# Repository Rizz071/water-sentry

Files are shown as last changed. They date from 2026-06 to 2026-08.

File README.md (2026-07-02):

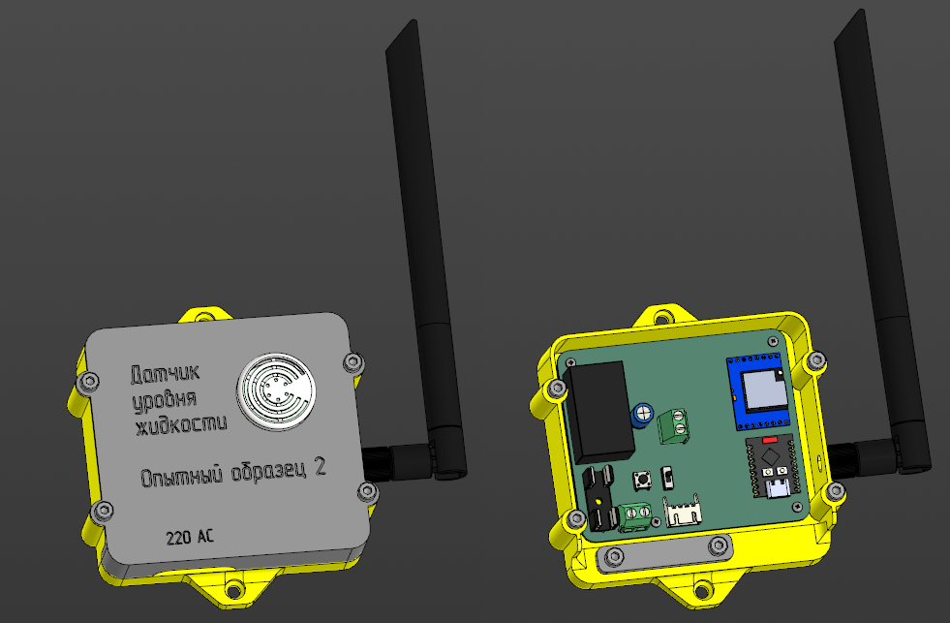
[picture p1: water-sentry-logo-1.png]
Блок управления датчиком уровня жидкости


# WaterSentry 🌊🏹

**WaterSentry** — это полностью автономная система дальнего беспроводного мониторинга уровня жидкости и предотвращения затоплений. 

Проект разработан для условий, где **абсолютно недоступны или ненадежны классические каналы связи**: нет Wi-Fi, интернета, сотовых сетей (GSM) и абонентской платы. Связь между удаленным датчиком и базовой станцией осуществляется напрямую по радиоканалу LoRa.

---

## 💡 Как это работает

1. **Удаленный датчик** устанавливается в месте возможного разлива (подвал, колодец, резервуар, насосная). Раз в 5 минут он отправляет короткий сигнал «я жив» (*heartbeat*).
2. **В случае перелива** датчик мгновенно выходит из режима ожидания и отправляет внеочередной пакет с флагом аварии.
3. **Базовая станция**, находящаяся на значительном удалении (в доме, диспетчерской), принимает сигнал, включает световую индикацию тревоги и запускает мощную сирену (зуммер) для привлечения внимания человека.

---

## 🚀 Ключевые особенности

* **Независимость от инфраструктуры:** Никаких сим-карт, роутеров и облачных сервисов. Прямая связь «точка-точка».
* **Огромная дальность:** Благодаря модулям LoRa на частоте 433 МГц сигнал уверенно пробивает железобетонные перекрытия, стены и распространяется на большие расстояния в условиях сложного рельефа.
* **Экстремальный минимализм протокола:** Данные упакованы в компактную структуру размером всего **6 байт**. Это минимизирует время работы передатчика в эфире (*Time on Air*), повышает пробивную способность радиосигнала и экономит энергию.
* **Промышленная надежность:** Код написан на **чистом Си** под нативный фреймворк **ESP-IDF v5.x**.
* **Гибкая отладка

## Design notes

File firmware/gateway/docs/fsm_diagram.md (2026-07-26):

# Water Sentry Gateway — State Machine Diagram

## Sensor Slot FSM (per slot, 5 independent instances)

```mermaid
stateDiagram-v2
    direction TB

    [*] --> EMPTY : Power on / no saved MAC

    state EMPTY {
        [*] --> Idle_Empty
    }
    note right of EMPTY : LED: OFF\nBuzzer: SILENT

    state PAIRING {
        [*] --> Waiting
    }
    note right of PAIRING : LED: BLUE\nBuzzer: SILENT\nTimeout: 60 sec

    state OK {
        [*] --> Normal
    }
    note right of OK : LED: GREEN\nBuzzer: SILENT\nPing → brief blink-off (100ms)

    state OFFLINE {
        [*] --> Lost
    }
    note right of OFFLINE : LED: YELLOW\nBuzzer: WARNING (beep)\nShort press → ack buzzer

    state ALARM {
        [*] --> WaterDetected
    }
    note right of ALARM : LED: RED\nBuzzer: ALARM (slow beep)

    %% Transitions from EMPTY
    EMPTY --> PAIRING : Short press button\n(empty slot)

    %% Transitions from PAIRING
    PAIRING --> OK : Pairing packet received\nfrom sensor
    PAIRING --> EMPTY : Short press (cancel)\nOR 60s timeout\n→ mac_addr cleared, NVS saved

    %% Transitions from OK
    OK --> ALARM : Water alarm packet\n(STATUS_BIT_ALARM_WATER)
    OK --> OFFLINE : No packets for\nSENSOR_TIMEOUT_MS (30s)
    OK --> PAIRING : Long press (≥3s)\n→ mac_addr cleared, NVS saved

    %% Transitions from OFFLINE
    OFFLINE --> OK : Any packet received\nfrom sensor
    OFFLINE --> EMPTY : Long press (≥3s)\n→ mac_addr cleared, NVS saved\n(forced in system_manager)

    %% Transitions from ALARM
    ALARM --> OK : Ping packet (no alarm)\nfrom sensor
    ALARM --> OFFLINE : No packets for\nSENSOR_TIMEOUT_MS (30s)
```

### Valid transition matrix (from `sensor_fsm.c`)

| From ↓ \ To → | EMPTY | PAIRING | OK | OFFLINE | ALARM |
|:---|:---:|:---:|:---:|:---:|:---:|
| **EMPTY** | — | ✅ | — | — | — |
| **PAIRING** | ✅ | — | ✅ | — | — |
| **OK** | — | ✅ | — | ✅ | ✅ |
| **OFFLINE** | ✅ | — | ✅ | — | — |
| **ALARM** | — | — | ✅ | ✅ | — |

> **Note:** `OFFLINE → PAIRING` is **not** in `sensor_fsm.c`'s `is_valid_transition()`.  
> It is forced directly in `system_manager.c` (long press handler) by clearing `mac_addr` and setting `state = SLOT_PAIRING` manually, bypassing `set_state()`.

---

## Button Event Flow

```mermaid
flowchart TD
    Press[Button Press\n(hardware-debounced)] --> HoldCheck{Held ≥ 3000ms?}

    HoldCheck -->|Yes| LongPress[EVENT_BTN_LONG_PRESS]
    HoldCheck -->|No, released| ShortPress[EVENT_BTN_PAIR_PRESSED]

    ShortPress --> SlotState{Slot State?}
    SlotState -->|EMPTY| StartPairing[Enter PAIRING]
    SlotState -->|PAIRING| CancelPairing[Cancel → EMPTY\nSave NVS]
    SlotState -->|OFFLINE| AckBuzzer[Acknowledge buzzer\noffline_acked = true]
    SlotState -->|OK / ALARM| Ignore[Do nothing]

    LongPress --> BoundCheck{Slot State?}
    BoundCheck -->|OK / ALARM / OFFLINE| ForcePairing[Clear mac_addr\nEnter PAIRING\nSave NVS]
    BoundCheck -->|EMPTY / PAIRING| Ignore2[Do nothing]
```

### Button timing constants (from `app_config.h`)

| Parameter | Value | Description |
|---|---|---|
| `BUTTON_POLL_MS` | 20 ms | ADC polling interval |
| Long press threshold | 3000 ms | Hardcoded in `buttons_service.c` |

---

## System Boot Sequence

```mermaid
sequenceDiagram
    participant Main as app_main()
    participant NVS as NVS HAL
    participant Buzzer as Buzzer HAL
    participant LED as LED Strip HAL
    participant Bus as Event Bus
    participant FSM as Sensor FSM
    participant Mgr as System Manager
    participant UI as UI Controller
    participant LoRa as LoRa Service
    participant BTN as Buttons Service

    Main->>NVS: nvs_hal_init()
    Main->>Buzzer: buzzer_hal_init()
    Note over Buzzer: Creates buzzer_task (prio 3)
    Main->>LED: led_strip_hal_init()
    Main->>Bus: event_bus_init()
    Main->>NVS: nvs_hal_load_blob("sensors", "dev_list")
    Main->>FSM: sensor_fsm_init(slots, mac_list, 5)
    Main->>Mgr: system_manager_init(slots, 5)
    Note over Mgr: Creates sys_manager_task (prio 5)
    Main->>UI: ui_controller_init()
    Note over UI: Creates ui_task (prio 3)
    Main->>LoRa: lora_service_init()
    Note over LoRa: Creates lora_rx_task (prio 5)
    Main->>BTN: buttons_service_init()
    Note over BTN: Creates buttons_polling_task (prio 5)
```

---

## System Architecture — Event Flow

```mermaid
flowchart LR
    subgraph HAL["Hardware Abstraction Layer"]
        LORA_HAL[LoRa HAL\nSX1278 SPI]
        BTN_HAL[Buttons HAL\nADC read]
        LED_HAL[LED Strip HAL\nRMT driver]
        BUZZ_HAL[Buzzer HAL\nGPIO + timer\n<buzzer_task>]
        NVS_HAL[NVS HAL\nFlash storage]
    end

    subgraph SERVICES["Service Layer"]
        LORA_SVC[LoRa Service\nFreeRTOS task\n<lora_rx_task>]
        BTN_SVC[Buttons Service\nFreeRTOS task\n<buttons_polling_task>\n+ debounce + long press]
        UI_CTRL[UI Controller\nFreeRTOS task\n<ui_task> 50ms\nLED + Buzzer]
        EV_BUS{{Event Bus\nFreeRTOS queue}}
        SYS_MGR[System Manager\nFreeRTOS task\n<sys_manager_task> 1s\nOrchestrator]
        FSM[Sensor FSM\nPure logic\n5 slots]
    end

    LORA_HAL -->|lora_rx_packet_t| LORA_SVC
    BTN_HAL -->|uint8_t raw| BTN_SVC

    LORA_SVC -->|EVENT_LORA_PACKET_RX| EV_BUS
    BTN_SVC -->|EVENT_BTN_PAIR_PRESSED| EV_BUS
    BTN_SVC -->|EVENT_BTN_LONG_PRESS| EV_BUS

    EV_BUS -->|event_t| SYS_MGR
    SYS_MGR -->|read/write state| FSM
    SYS_MGR -->|save/load| NVS_HAL

    FSM -->|sensor_slot_t[5]| UI_CTRL
    UI_CTRL -->|led_color_t[5]| LED_HAL
    UI_CTRL -->|buzzer_state_t| BUZZ_HAL
```

---

## Event Bus — Message Catalog

| Event Type | Producer | Consumer | Payload |
|---|---|---|---|
| `EVENT_BTN_PAIR_PRESSED` | Buttons Service | System Manager | `button_num` (1..5) |
| `EVENT_BTN_LONG_PRESS` | Buttons Service | System Manager | `button_num` (1..5) |
| `EVENT_LORA_PACKET_RX` | LoRa Service | System Manager | `mac_addr`, `packet_type` (status bits) |
| `EVENT_PERIODIC_TICK` | System Manager (self) | System Manager | — (generated on queue timeout) |
| `EVENT_PAIRING_TIMEOUT` | System Manager (self) | System Manager | — (generated on queue timeout) |

---

## LED Color Map

| State | Red | Green | Blue | Visual |
|---|-----|---|---|---|
| EMPTY | 0 | 0 | 0 | ⚫ Off |
| PAIRING | 0 | 0 | 255 | 🔵 Blue |
| OK | 0 | 255 | 0 | 🟢 Green |
| OK (ping blink) | 0 | 0 | 0 | ⚫ Brief off (100ms) |
| OFFLINE | 0 | 255 | 255 | 🟡 Yellow (Green+Blue) |
| ALARM | 255 | 0 | 0 | 🔴 Red |

---

## Buzzer Patterns

| Condition | Pattern | Code Constant | Meaning |
|---|---|---|---|
| Any ALARM slot | 1000ms ON / 1000ms OFF | `BUZZER_STATE_ALARM` | Water leak detected |
| Unacked OFFLINE slot(s) | 200ms ON / 200ms OFF | `BUZZER_STATE_WARNING` | Sensor connection lost |
| All OFFLINE acked / no issues | OFF (always low) | `BUZZER_STATE_SILENCED` | Normal operation |

### Buzzer state priority (in `ui_controller.c`)

```
has_alarm → BUZZER_STATE_ALARM       (highest)
has_unacked_offline → BUZZER_STATE_WARNING
else → BUZZER_STATE_SILENCED         (lowest)
```

---

## Task List (FreeRTOS)

| Task | Stack | Priority | Period | WDT | Created by |
|---|---|---|---|-----|---|
| `lora_rx_task` | 3072 | 5 | ~10ms (poll) | ✅ | `lora_service_init()` |
| `buttons_polling_task` | 3072 | 5 | 20ms | ✅ | `buttons_service_init()` |
| `sys_manager_task` | 4096 | 5 | 1s (event timeout) | ✅ | `system_manager_init()` |
| `ui_task` | 3072 | 3 | 50ms | ✅ | `ui_controller_init()` |
| `buzzer_task` | 3072 | 3 | varies (100ms/400ms/2000ms) | ✅ | `buzzer_hal_init()` |

### Task periods for buzzer_task (from `buzzer_hal.c`)

| Buzzer State | Cycle | vTaskDelay |
|---|---|---|
| `BUZZER_STATE_SILENCED` | OFF → wait 100ms → repeat | 100ms |
| `BUZZER_STATE_WARNING` | ON 200ms → OFF 200ms → repeat | 200ms |
| `BUZZER_STATE_ALARM` | ON 1000ms → OFF 1000ms → repeat | 1000ms |

---

## Configuration Constants (from `app_config.h`)

| Constant | Value | Description |
|---|---|---|
| `MAX_SENSORS` | 5 | Number of sensor slots |
| `EVENT_QUEUE_LENGTH` | 10 | System event queue capacity |
| `LORA_RX_QUEUE_LENGTH` | 20 | LoRa RX packet queue capacity |
| `BUTTON_POLL_MS` | 20 ms | ADC polling interval |
| `SENSOR_TIMEOUT_MS` | 30000 ms (30s) | Sensor considered offline after this |
| `PAIRING_TIMEOUT_MS` | 60000 ms (60s) | Pairing mode auto-cancel |

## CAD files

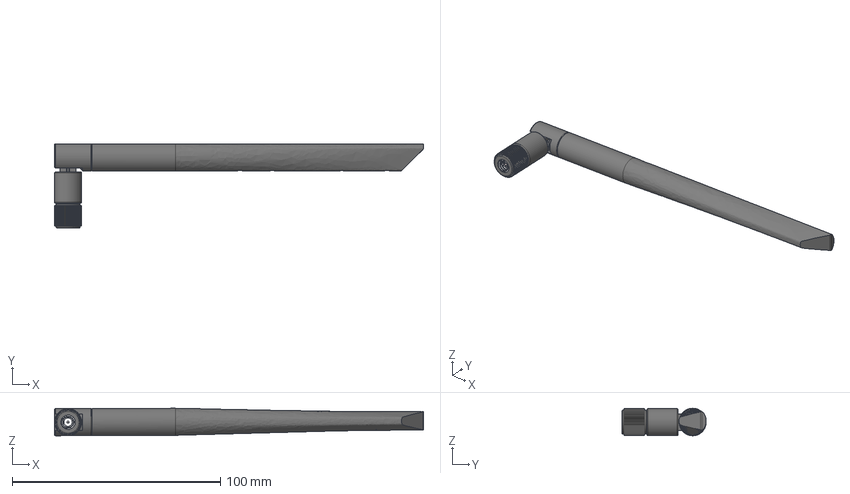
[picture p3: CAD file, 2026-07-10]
hardware/gateway/enclosure/Antenna 868mhz 5dbi 90dg.step
177.0 x 40.5 x 13.2 mm
SMA sleeve
SMA
Sleeve yoke
emitter yoke
emitter tube
emitter cover

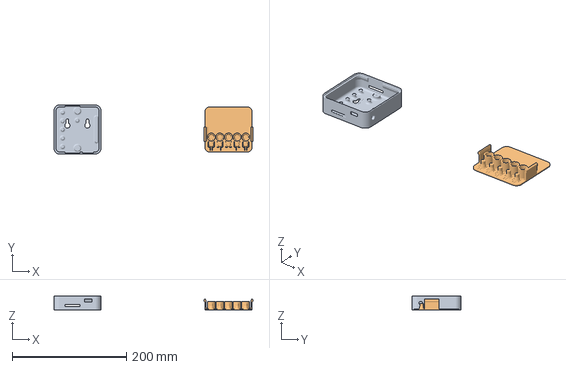
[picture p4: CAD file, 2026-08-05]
hardware/gateway/enclosure/Manufacture/Базовая станция Исп 1.3mf
347.8 x 86.0 x 25.0 mm
Корпус блока управления датчика уровня жидкости.stp
Крышка корпуса базовой станции.stp

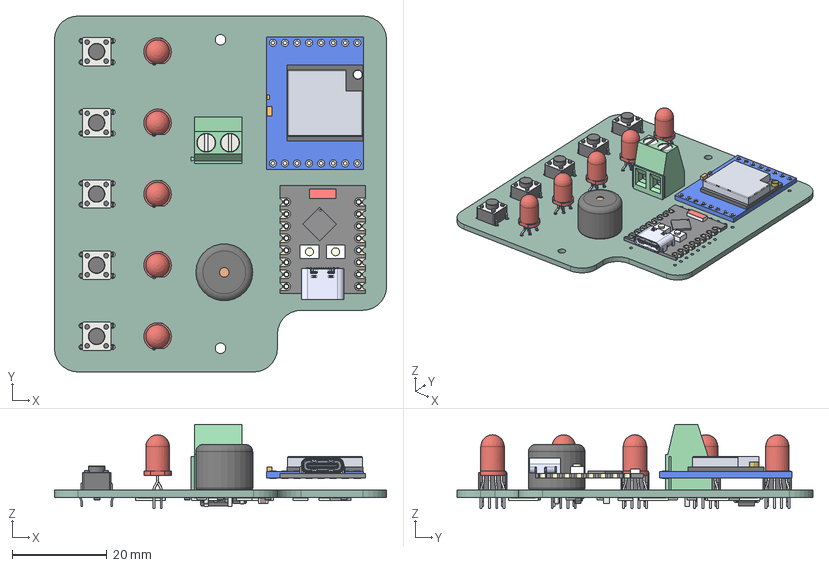
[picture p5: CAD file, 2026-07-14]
hardware/gateway/KiCAD/sensor_3d.step
70.0 x 75.0 x 17.8 mm
SW_PUSH_6mm_h5mm x 5
Buzzer_12x95RM76
LED_D5.0mm-4_RGB_Staggered_Pins x 5
TerminalBlock_Phoenix_MKDS-1,5-2_1x02_P5.00mm_Horizontal
Board c3mini
USB C
components (other)^ESP32-C3 SuperMini
R_2512_6332Metric x 8
R_0805_2012Metric x 10
SOT-23
C_0805_2012Metric
SOT-223
gatFA11_PCB

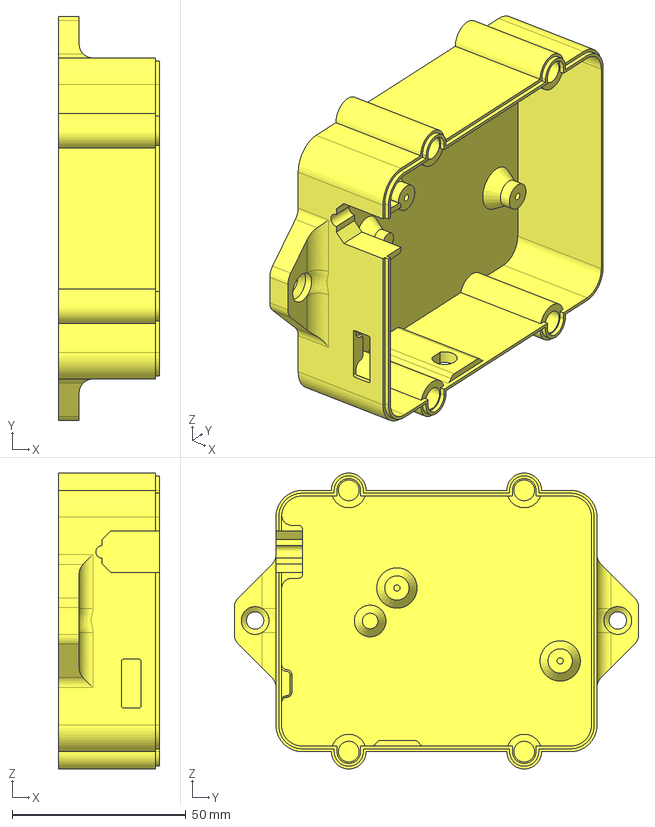
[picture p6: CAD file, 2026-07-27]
hardware/sensor/enclosure/Manufacture/Корпус блока управления датчика уровня жидкости.stp
29.2 x 116.4 x 85.2 mm

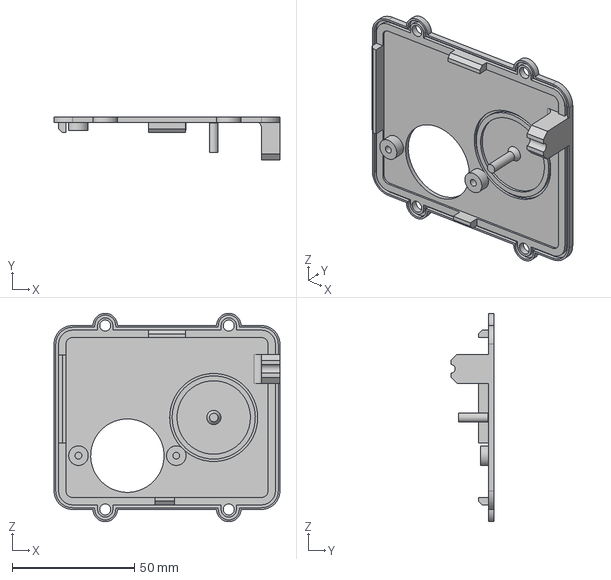
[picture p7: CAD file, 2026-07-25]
hardware/sensor/enclosure/Крышка блока управления датчиком уровня жидкости.stp
92.4 x 17.7 x 85.2 mm

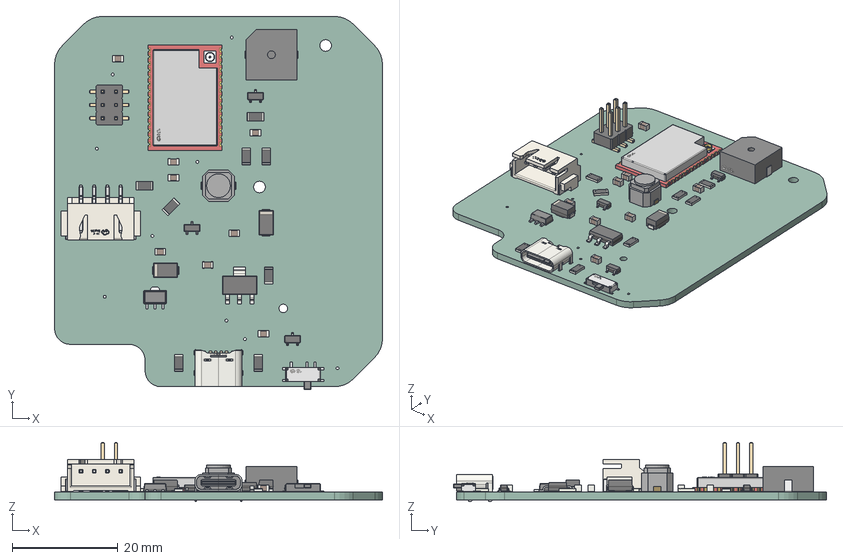
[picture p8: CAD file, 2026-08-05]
hardware/sensor/KiCAD/sensor_3d.step
62.0 x 70.6 x 11.2 mm
C_0805_2012Metric x 8
R_1206_3216Metric x 8
D_SMA x 2
SOT-23 x 3
PinHeader_2x03_P254mm_Vertical_SMD
COMM-SMD_30P-L20.0-W14.0-P1.27
USB_C_Receptacle_GCT_USB4125-xx-x_6P_TopMnt_Horizontal
BUZ-SMD_L9.6-W9.6-H5.0
pin_1
pin_2
SOT-89-3_L4.3-W2.5-H1.6-LS4.1-P1.50
SW-SMD_3P-L6.6-W2.7-LS7.8-P1.50
CONN-SMD_XH2.50-WS-4P
SOT-223
active_sender_PCB

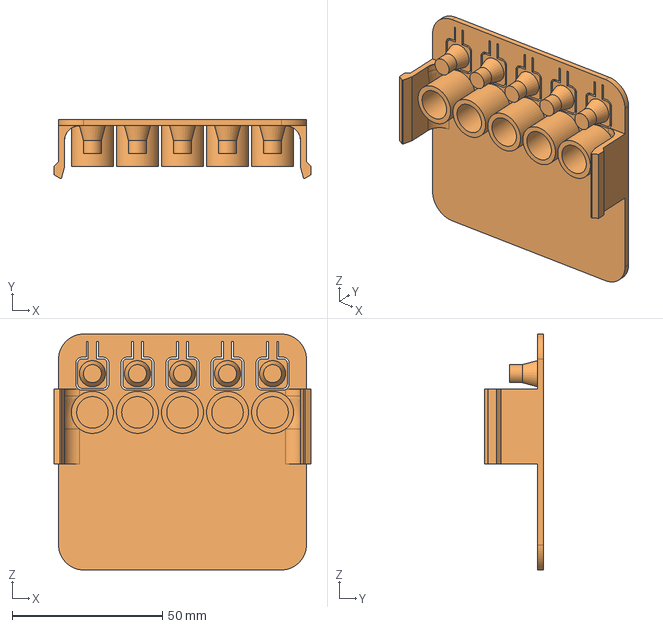
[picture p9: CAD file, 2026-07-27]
hardware/gateway/enclosure/Manufacture/Крышка корпуса базовой станции.stp
85.6 x 19.5 x 78.6 mm

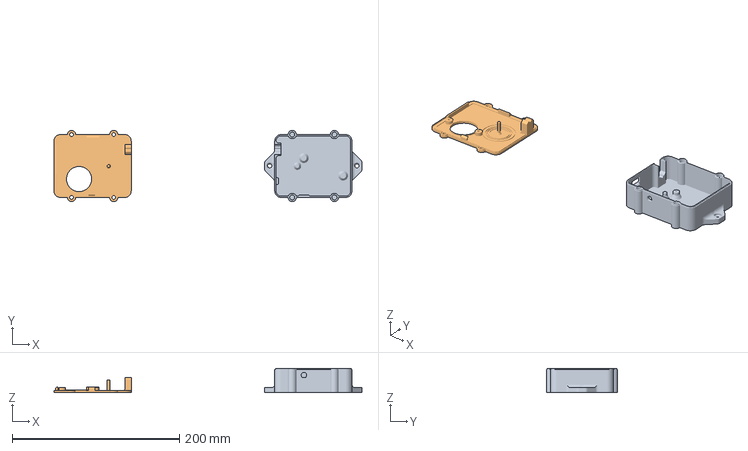
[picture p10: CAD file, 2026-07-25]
hardware/sensor/enclosure/Manufacture/Блок управления датчиком уровня жидкости.3mf
368.4 x 85.2 x 29.2 mm
Корпус блока управления датчика уровня жидкости.stp
Крышка блока управления датчиком уровня жидкости.stp

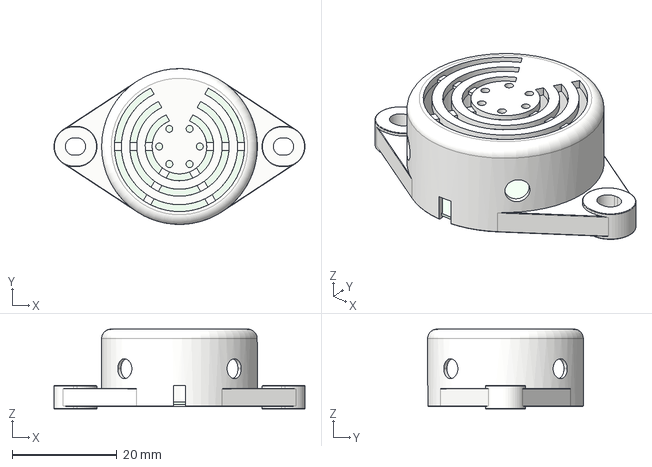
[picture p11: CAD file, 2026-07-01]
hardware/sensor/enclosure/Piezo Buzzer (3-24v, M3).step
48.0 x 29.8 x 15.3 mm

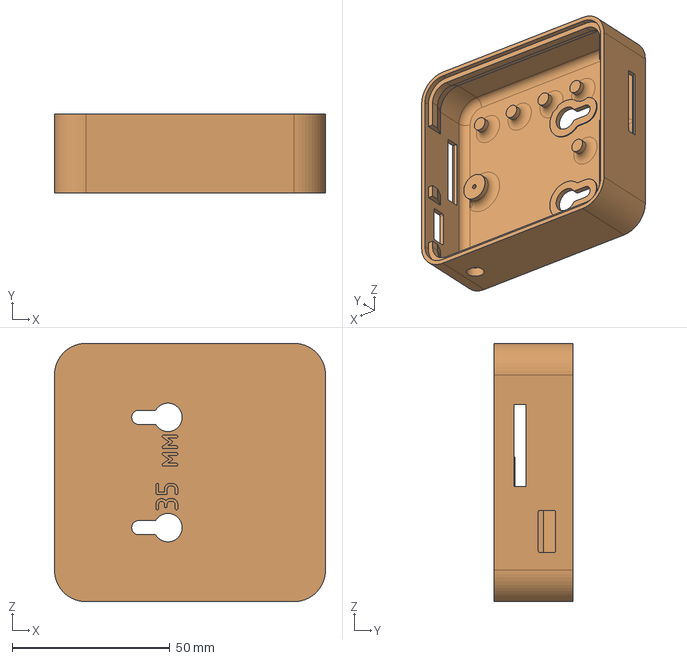
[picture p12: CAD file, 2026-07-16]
hardware/gateway/enclosure/Manufacture/Корпус блока управления датчика уровня жидкости.stp
86.0 x 25.0 x 82.0 mm

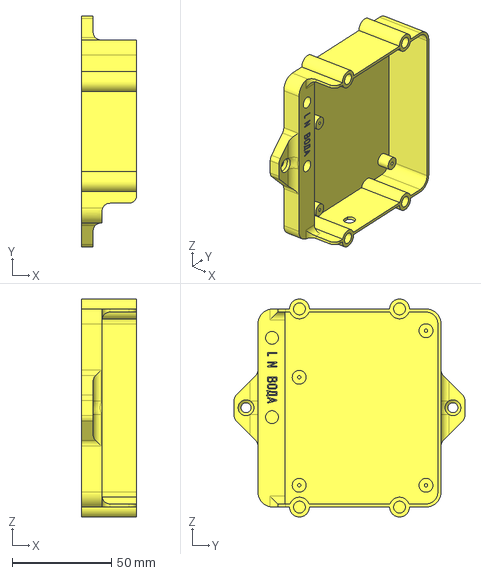
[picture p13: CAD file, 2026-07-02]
hardware/gateway/enclosure/Корпус блока управления датчика уровня жидкости.stp
28.0 x 116.4 x 110.0 mm

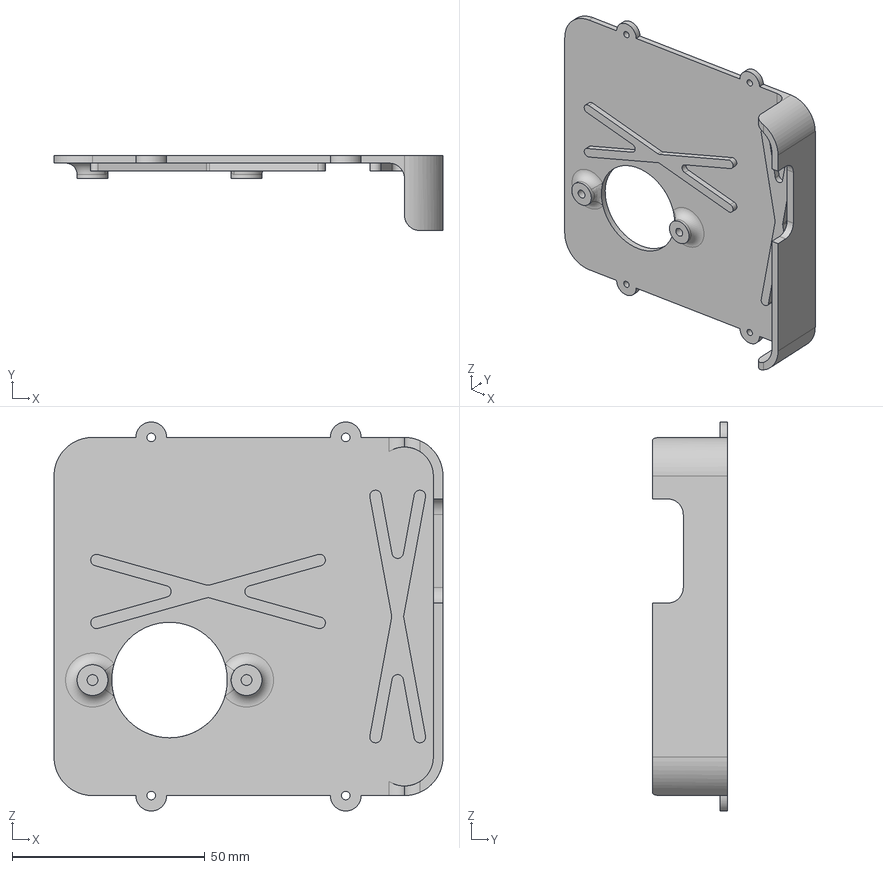
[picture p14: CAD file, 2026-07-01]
hardware/gateway/enclosure/Manufacture/Крышка блока управления датчиком уровня жидкости.stp
101.0 x 19.5 x 101.0 mm

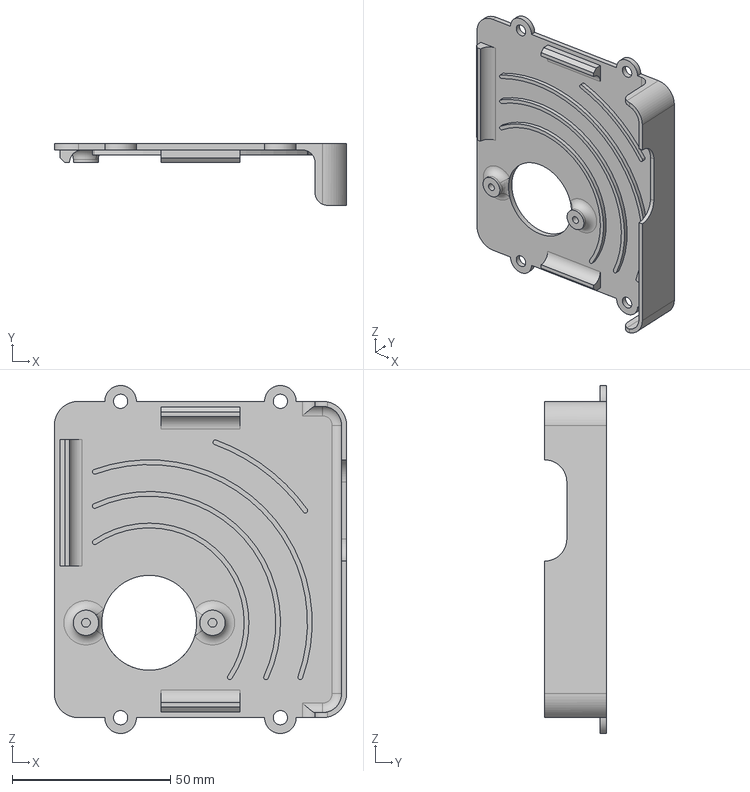
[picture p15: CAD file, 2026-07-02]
hardware/gateway/enclosure/Крышка блока управления датчиком уровня жидкости.stp
92.4 x 19.5 x 110.0 mm

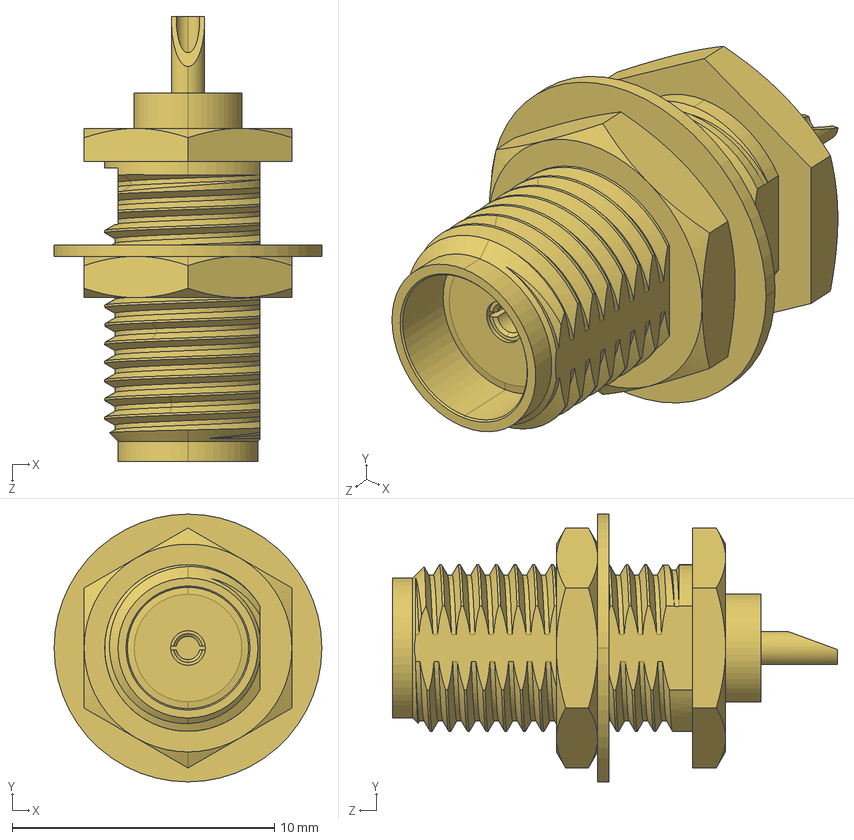
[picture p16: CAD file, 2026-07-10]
hardware/gateway/enclosure/1053072-1.STEP
10.2 x 10.2 x 17.0 mm

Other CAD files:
hardware/sensor/enclosure/Manufacture/Крышка блока управления датчиком уровня жидкости.stp
hardware/gateway/KiCAD/sensor_3d.stl
hardware/sensor/KiCAD/sensor_3d.stl

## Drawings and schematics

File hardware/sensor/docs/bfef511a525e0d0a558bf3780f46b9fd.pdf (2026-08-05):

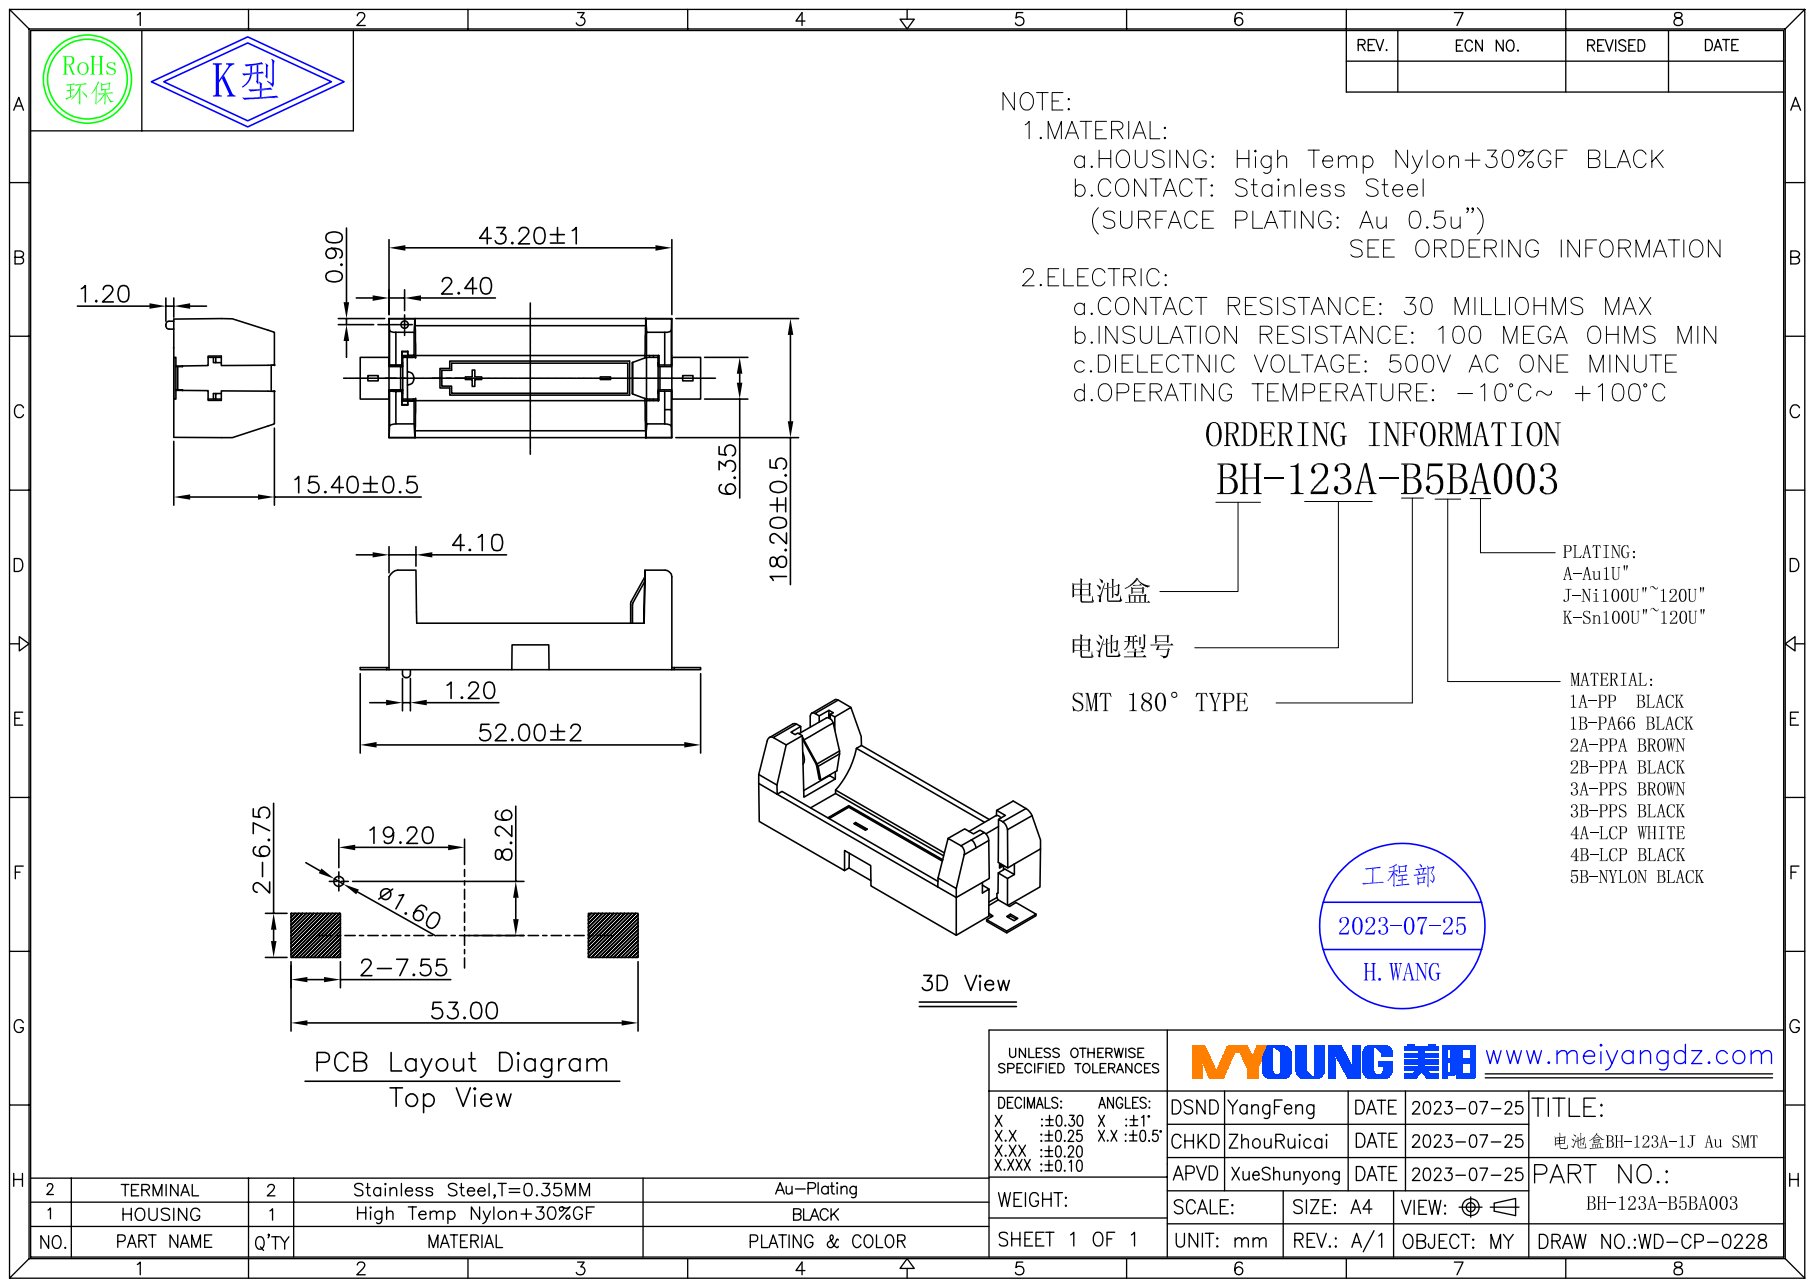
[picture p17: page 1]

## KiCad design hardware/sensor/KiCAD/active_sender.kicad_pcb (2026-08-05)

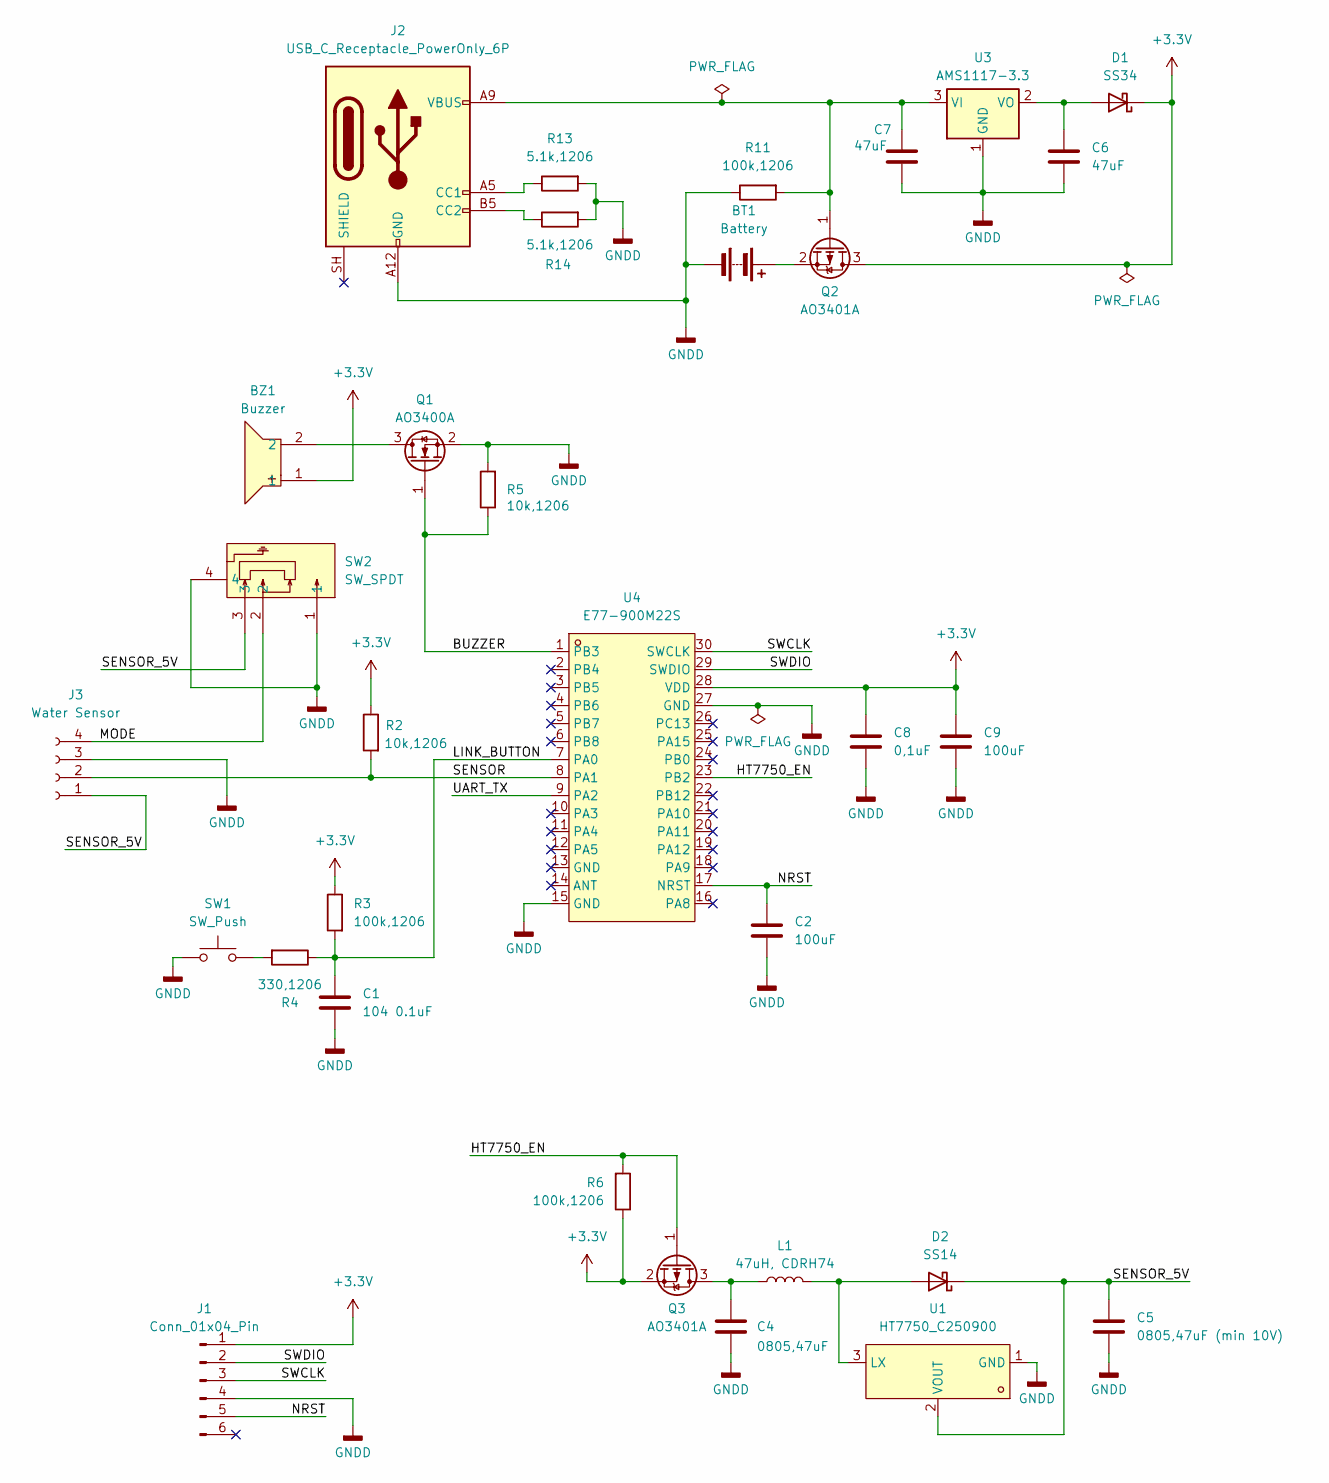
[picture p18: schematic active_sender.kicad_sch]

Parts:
BT1: Battery; CR123A-SMD_BH-123A-B5BA003
BZ1: Buzzer; Huaneng MLT-9650; MPN MLT-9650; LCSC Part C96127
C1: 104 0.1uF; C_0805_2012Metric_Pad1.18x1.45mm_HandSolder
C2, C9: 100uF; C_0805_2012Metric_Pad1.18x1.45mm_HandSolder
C4: 0805,47uF; C_0805_2012Metric_Pad1.18x1.45mm_HandSolder
C5: 0805,47uF (min 10V); C_0805_2012Metric_Pad1.18x1.45mm_HandSolder
C6, C7: 47uF; C_0805_2012Metric_Pad1.18x1.45mm_HandSolder
C8: 0,1uF; C_0805_2012Metric_Pad1.18x1.45mm_HandSolder
D1: SS34; D_SMA
D2: SS14; D_SMA
J1: Conn_01x04_Pin; PinHeader_2x03_P2.54mm_Vertical_SMD
J2: USB_C_Receptacle_PowerOnly_6P; USB_C_Receptacle_GCT_USB4125-xx-x-0190_6P_TopMnt_Horizontal
J3: Water Sensor; JST_XH_S4B-XH-SM4-TB_1x04-1MP_P2.50mm_Horizontal
L1: 47uH, CDRH74; L_7.3x7.3_H4.5
Q1: AO3400A; SOT-23
Q2, Q3: AO3401A; SOT-23
R2, R5: 10k,1206; R_1206_3216Metric_Pad1.30x1.75mm_HandSolder
R3, R6, R11: 100k,1206; R_1206_3216Metric_Pad1.30x1.75mm_HandSolder
R4: 330,1206; R_1206_3216Metric_Pad1.30x1.75mm_HandSolder
R13, R14: 5.1k,1206; R_1206_3216Metric_Pad1.30x1.75mm_HandSolder
SW1: SW_Push; SW_Push_1TS009xxxx-xxxx-xxxx_6x6x5mm
SW2: SW_SPDT; MSK12-C02; MPN MSK12C02; LCSC Part C431540
U1: HT7750_C250900; HT7750; MPN HT7750; LCSC Part C250900
U3: AMS1117-3.3; SOT-223-3_TabPin2
U4: E77-900M22S; COMM-SMD_30P-L20.0-W14.0-P1.27; MPN E77-900M22S; LCSC Part C5124422

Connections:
+3.3V: BZ1.1, C8.1, C9.1, D1.1 (K), J1.1, Q2.3 (D), Q3.2 (S), R2.1, R3.1, R6.1, U4.28 (VDD)
/BUZZER: Q1.1 (G), R5.1, U4.1 (PB3)
/HT7750_EN: Q3.1 (G), R6.2, U4.23 (PB2)
/LINK_BUTTON: C1.1, R3.2, R4.1, U4.7 (PA0)
/MODE: J3.4, SW2.2
/NRST: C2.1, J1.5, U4.17 (NRST)
/SENSOR: J3.2, R2.2, U4.8 (PA1)
/SENSOR_5V: C5.1, D2.1 (K), J3.1, SW2.3, U1.2 (VOUT)
/SWCLK: J1.3, U4.30 (SWCLK)
/SWDIO: J1.2, U4.29 (SWDIO)
/UART_TX: U4.9 (PA2)
GNDD: BT1.2 (-), C1.2, C2.2, C4.2, C5.2, C6.2, C7.2, C8.2, C9.2, J1.4, J2.A12 (GND), J2.B12 (GND), J3.3, Q1.2 (S), R5.2, R11.1, R13.2, R14.2, SW1.1, SW2.1, SW2.4, U1.1 (GND), U3.1 (GND), U4.15 (GND), U4.27 (GND)
unnamed: BT1.1 (+), Q2.2 (S)
unnamed: C6.1, D1.2 (A), U3.2 (VO)
unnamed: D2.2 (A), L1.2, U1.3 (LX)
unnamed: J2.A5 (CC1), R13.1
unnamed: J2.B5 (CC2), R14.1
unnamed: BZ1.2, Q1.3 (D)
unnamed: C7.1, J2.A9 (VBUS), J2.B9 (VBUS), Q2.1 (G), R11.2, U3.3 (VI)
unnamed: C4.1, L1.1, Q3.3 (D)
unnamed: R4.2, SW1.2

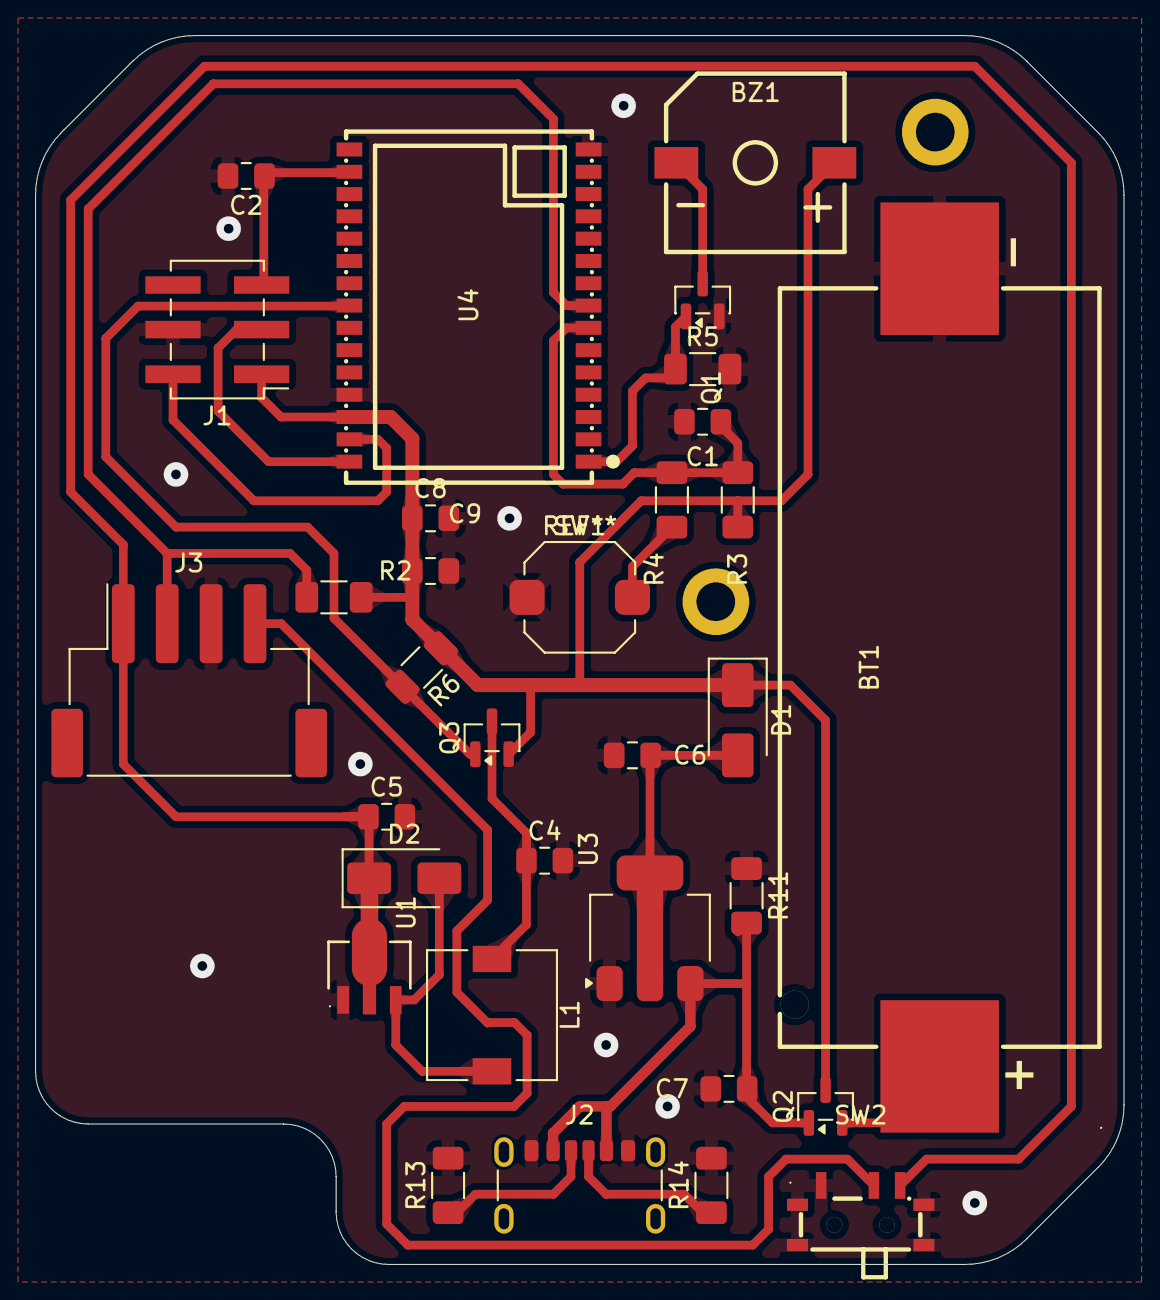
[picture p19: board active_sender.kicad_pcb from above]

Board: 2 copper layers, 62.0 x 70.0 mm, 32 parts (0 on the bottom side), 20 nets.

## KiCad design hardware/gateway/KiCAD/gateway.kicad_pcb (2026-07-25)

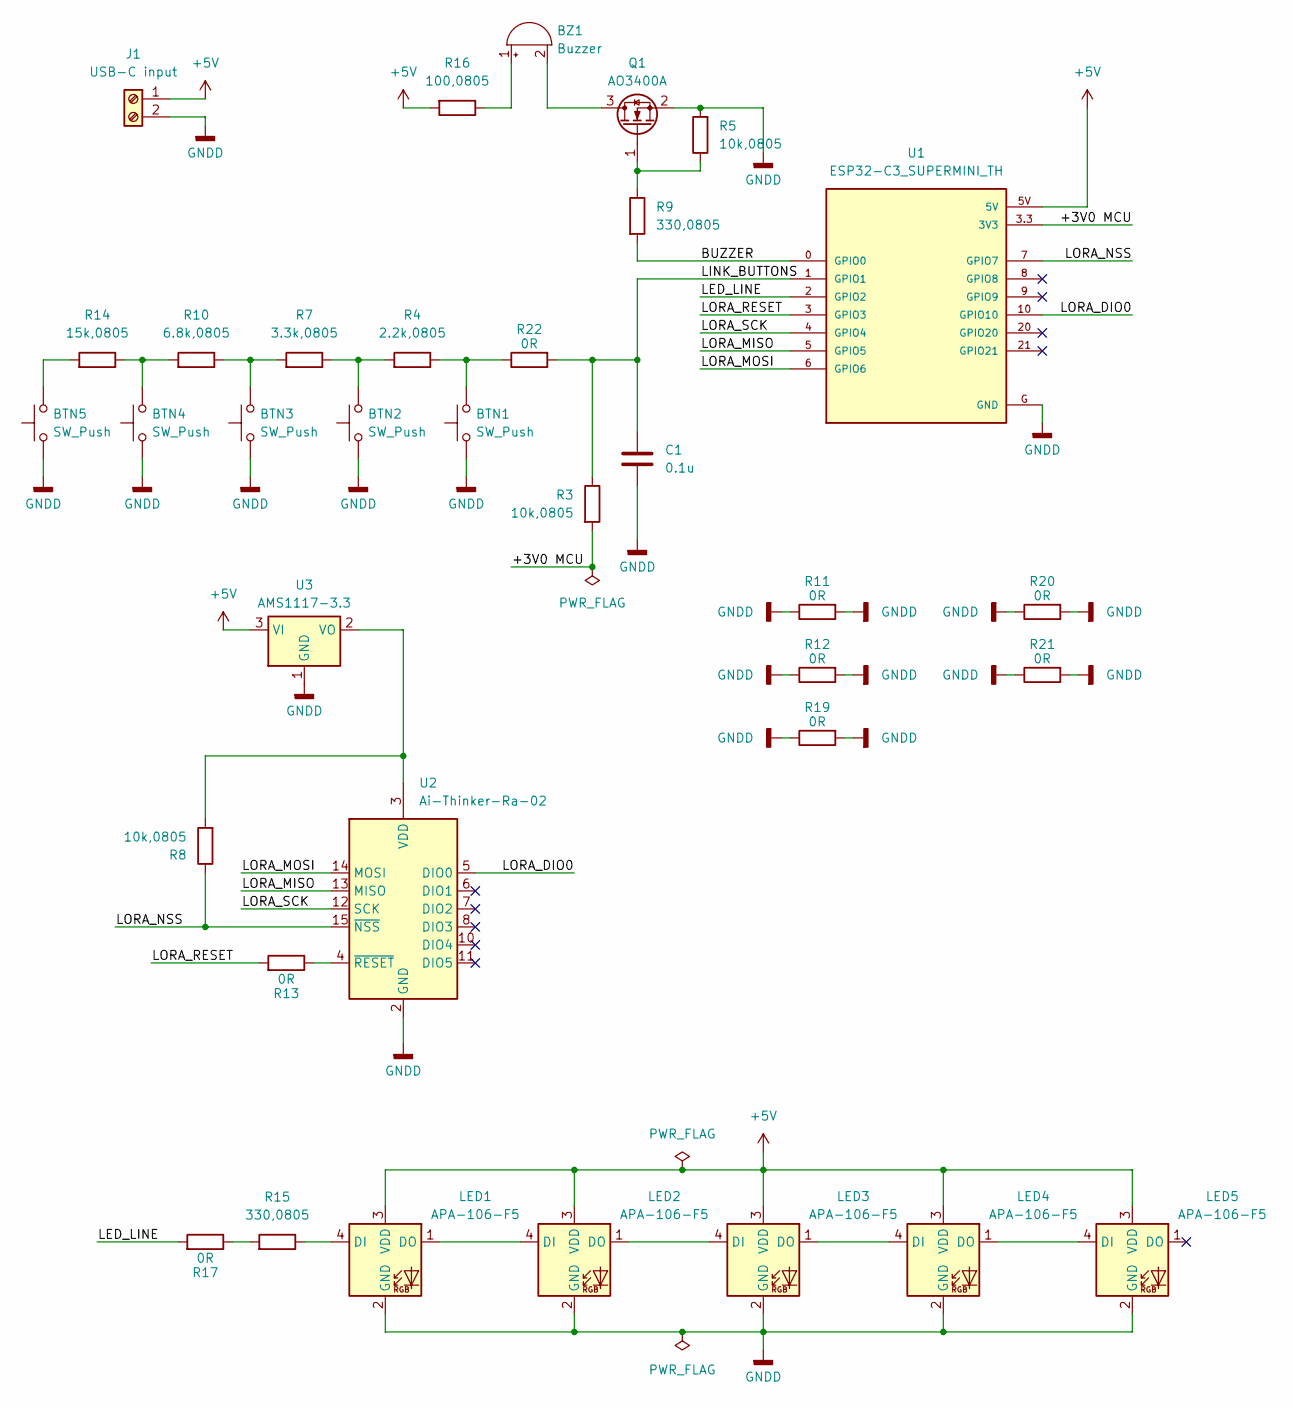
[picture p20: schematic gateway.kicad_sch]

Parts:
BTN1, BTN2, BTN3, BTN4, BTN5: SW_Push; SW_PUSH_6mm_H5mm
BZ1: Buzzer; Buzzer_12x9.5RM7.6
C1: 0.1u; C_0805_2012Metric_Pad1.18x1.45mm_HandSolder
J1: USB-C input; TerminalBlock_Phoenix_MKDS-1,5-2_1x02_P5.00mm_Horizontal
LED1, LED2, LED3, LED4, LED5: APA-106-F5; LED_D5.0mm-4_RGB_Staggered_Pins
Q1: AO3400A; SOT-23
R3, R5, R8: 10k,0805; R_0805_2012Metric_Pad1.20x1.40mm_HandSolder
R4: 2.2k,0805; R_0805_2012Metric_Pad1.20x1.40mm_HandSolder
R7: 3.3k,0805; R_0805_2012Metric_Pad1.20x1.40mm_HandSolder
R9, R15: 330,0805; R_0805_2012Metric_Pad1.20x1.40mm_HandSolder
R10: 6.8k,0805; R_0805_2012Metric_Pad1.20x1.40mm_HandSolder
R11, R12, R13, R17, R19, R20, R21, R22: 0R; R_2512_6332Metric_Pad1.40x3.35mm_HandSolder
R14: 15k,0805; R_0805_2012Metric_Pad1.20x1.40mm_HandSolder
R16: 100,0805; R_0805_2012Metric_Pad1.20x1.40mm_HandSolder
U1: ESP32-C3_SUPERMINI_TH; MODULE_ESP32-C3_SUPERMINI_TH
U2: Ai-Thinker-Ra-02; Ai-Thinker-Ra-01-LoRa BREAKOUT BOARD
U3: AMS1117-3.3; SOT-223-3_TabPin2

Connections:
+5V: J1.1, LED1.3 (VDD), LED2.3 (VDD), LED3.3 (VDD), LED4.3 (VDD), LED5.3 (VDD), R16.2, U1.5V, U3.3 (VI)
/+3V0 MCU: R3.2, U1.3.3 (3V3)
/BUZZER: R9.2, U1.0 (GPIO0)
/LED_LINE: R17.2, U1.2 (GPIO2)
/LINK_BUTTONS: C1.1, R3.1, R22.2, U1.1 (GPIO1)
/LORA_DIO0: U1.10 (GPIO10), U2.5 (DIO0)
/LORA_MISO: U1.5 (GPIO5), U2.13 (MISO)
/LORA_MOSI: U1.6 (GPIO6), U2.14 (MOSI)
/LORA_NSS: R8.1, U1.7 (GPIO7), U2.15 (~NSS)
/LORA_RESET: R13.2, U1.3 (GPIO3)
/LORA_SCK: U1.4 (GPIO4), U2.12 (SCK)
GNDD: BTN1.1, BTN2.1, BTN3.1, BTN4.1, BTN5.1, C1.2, J1.2, LED1.2 (GND), LED2.2 (GND), LED3.2 (GND), LED4.2 (GND), LED5.2 (GND), Q1.2 (S), R5.2, R11.1, R11.2, R12.1, R12.2, R19.1, R19.2, R20.1, R20.2, R21.1, R21.2, U1.G (GND), U2.1 (GND), U2.2 (GND), U2.9 (GND), U2.16 (GND), U3.1 (GND)
unnamed: BTN1.2, R4.1, R22.1
unnamed: BTN2.2, R4.2, R7.1
unnamed: BTN3.2, R7.2, R10.1
unnamed: BTN4.2, R10.2, R14.1
unnamed: BTN5.2, R14.2
unnamed: BZ1.1 (+), R16.1
unnamed: BZ1.2 (-), Q1.3 (D)
unnamed: LED1.4 (DI), R15.1
unnamed: LED1.1 (DO), LED2.4 (DI)
unnamed: LED2.1 (DO), LED3.4 (DI)
unnamed: LED3.1 (DO), LED4.4 (DI)
unnamed: LED4.1 (DO), LED5.4 (DI)
unnamed: Q1.1 (G), R5.1, R9.1
unnamed: R15.2, R17.1
unnamed: R8.2, U2.3 (VDD), U3.2 (VO)
unnamed: R13.1, U2.4 (~RESET)

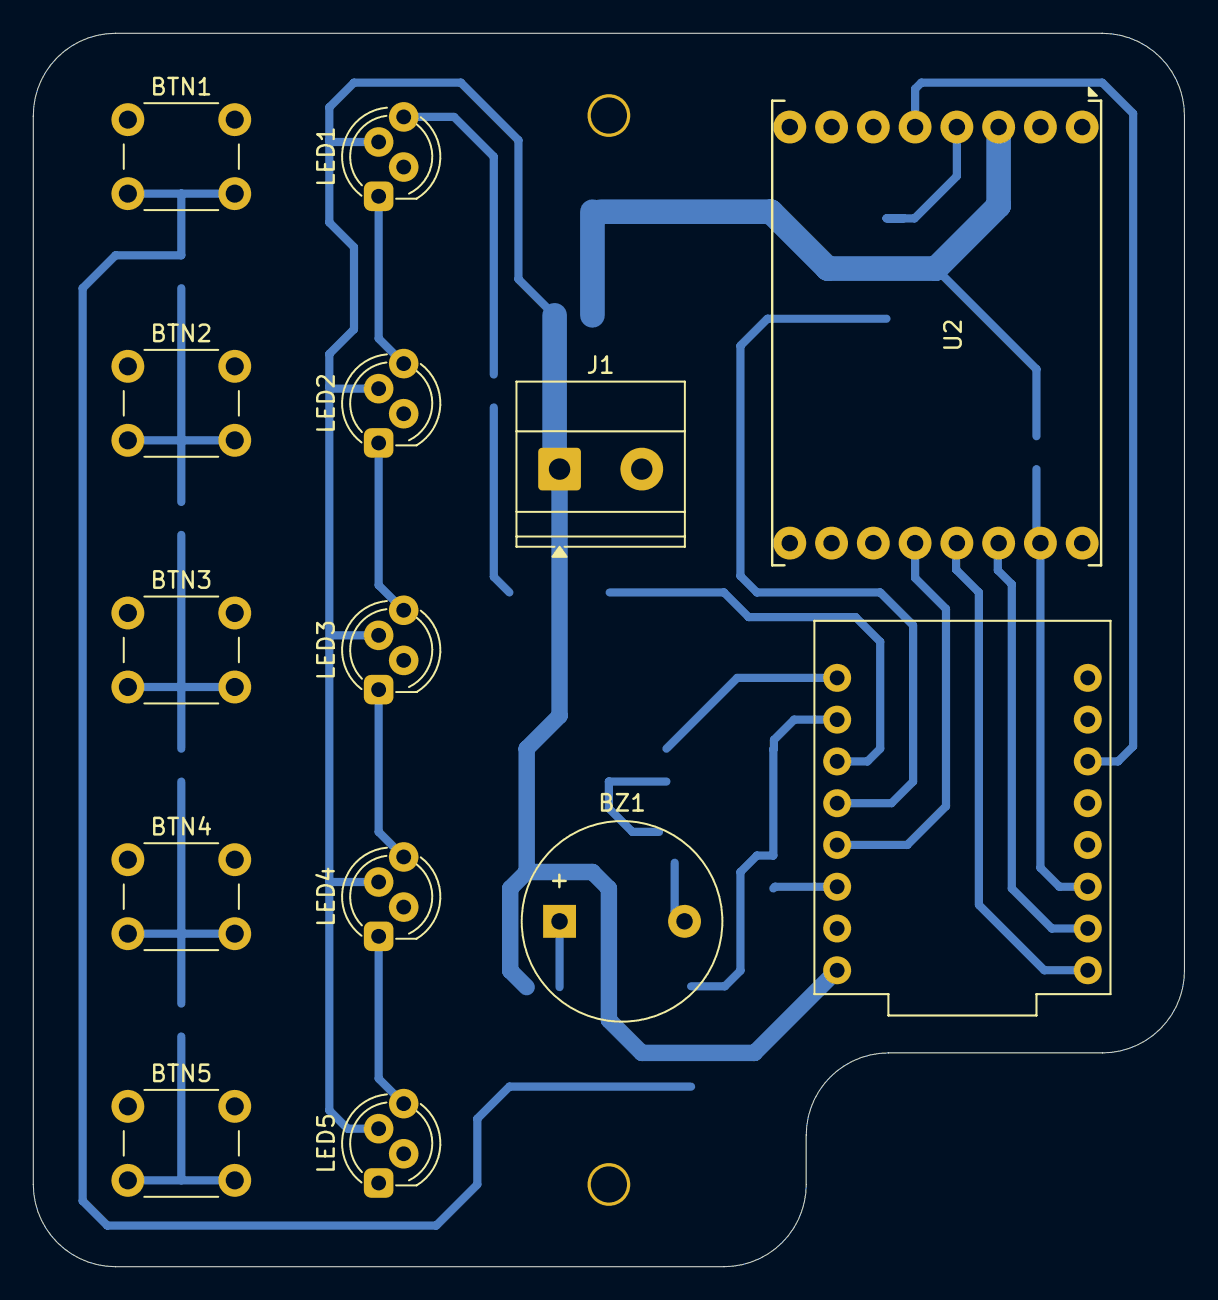
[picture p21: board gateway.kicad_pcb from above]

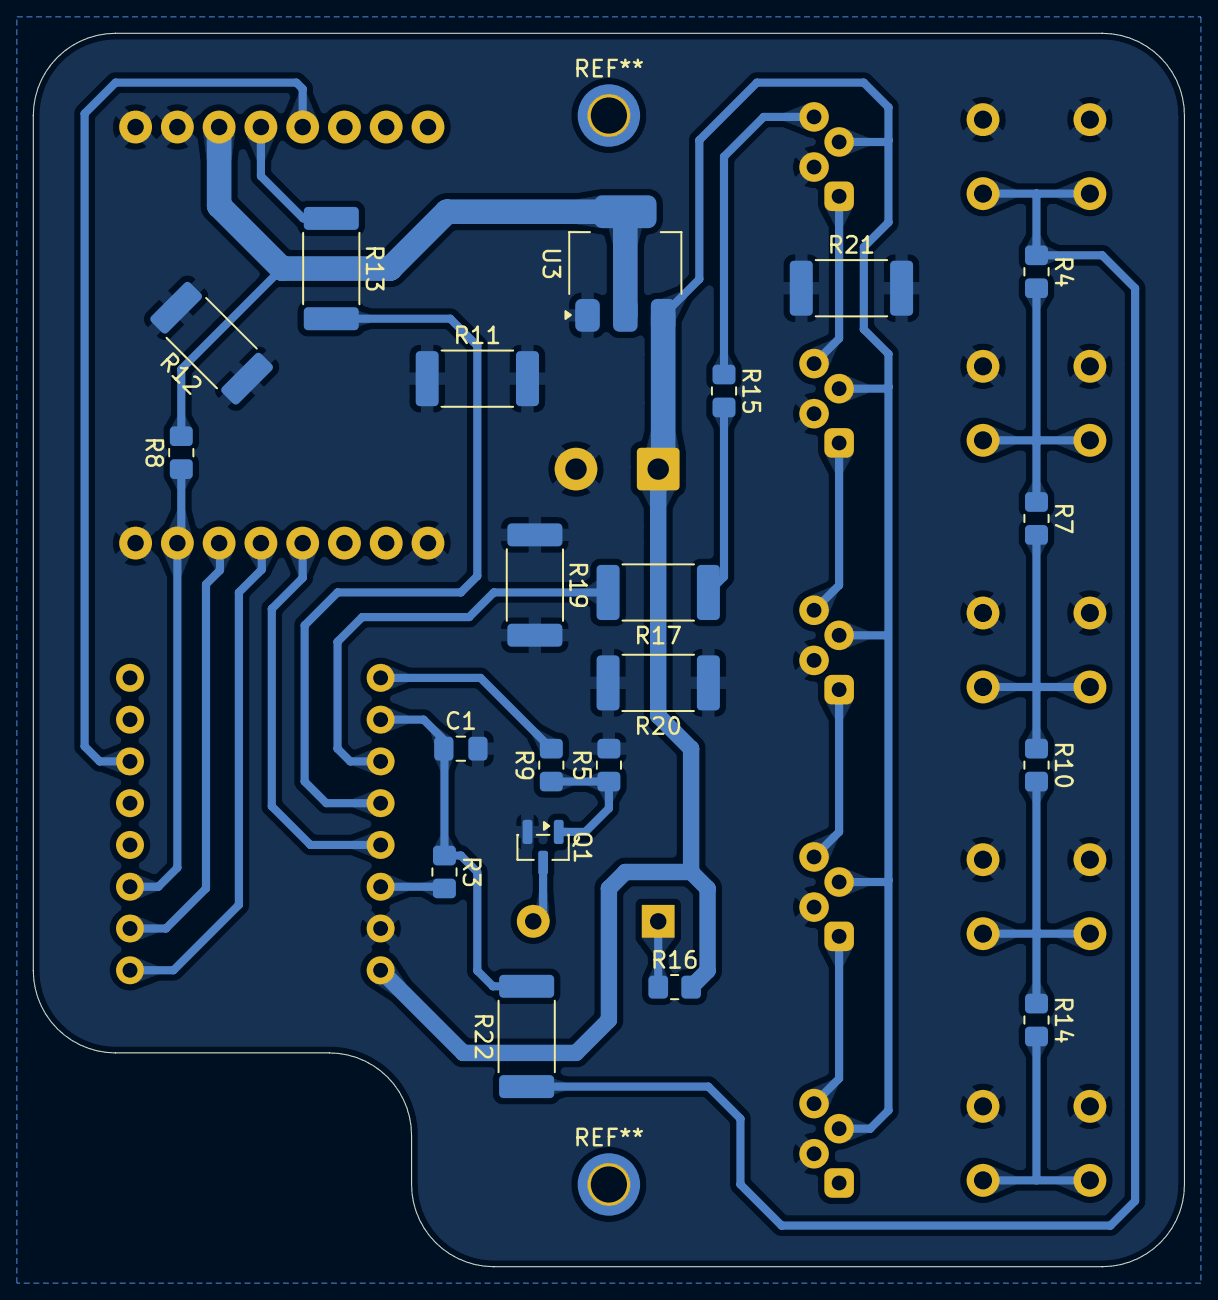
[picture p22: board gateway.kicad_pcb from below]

Board: 2 copper layers, 70.0 x 75.0 mm, 35 parts (21 on the bottom side), 28 nets.

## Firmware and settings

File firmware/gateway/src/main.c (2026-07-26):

#include "esp_log.h"
#include "freertos/FreeRTOS.h"
#include "freertos/task.h"
#include "gpio_mapping.h"
#include "app_config.h"

#include "hal/buzzer_hal.h"
#include "hal/led_strip_hal.h"
#include "hal/nvs_hal.h"
#include "service/event_bus.h"
#include "service/sensor_fsm.h"
#include "service/ui_controller.h"
#include "service/system_manager.h"
#include "service/lora_service.h"
#include "service/buttons_service.h"

static const char *TAG = "MAIN_APP";

void app_main(void)
{
    vTaskDelay(pdMS_TO_TICKS(3000));
    ESP_LOGI(TAG, "Water Sentry Gateway starting...");

    /* ======================================================================
     * LAYER 1: Hardware Abstraction (HAL) — init all peripherals
     * ====================================================================== */

    // NVS flash storage
    nvs_hal_init();

    // Buzzer
    static buzzer_hal_t buzzer;
    buzzer_hal_init(&buzzer, BUZZER_PIN);

    // LED strip
    static led_strip_hal_t led_strip;
    led_strip_hal_init(&led_strip, LED_LINE_PIN, MAX_SENSORS);

    /* ======================================================================
     * LAYER 2: Event bus — the communication backbone
     * ====================================================================== */
    event_bus_init();

    /* ======================================================================
     * LAYER 3: Sensor state machine — load persisted MACs
     * ====================================================================== */
    static sensor_slot_t slots[MAX_SENSORS];

    uint8_t mac_list[MAX_SENSORS];
    size_t mac_size = sizeof(mac_list);
    memset(mac_list, 0, mac_size);

    esp_err_t nvs_err = nvs_hal_load_blob("sensors", "dev_list", mac_list, &mac_size);
    if (nvs_err != ESP_OK)
    {
        ESP_LOGW(TAG, "No saved sensors found, starting with empty slots.");
    }

    for (size_t i = 0; i < MAX_SENSORS; i++)
    {
        ESP_LOGI(TAG, "Loaded MAC[%d]: 0x%02X", (int)i, mac_list[i]);
    }

    sensor_fsm_init(slots, mac_list, MAX_SENSORS);

    /* ======================================================================
     * LAYER 4: System manager — orchestrates FSM
     * ====================================================================== */
    system_manager_init(slots, MAX_SENSORS);

    /* ======================================================================
     * LAYER 4.5: UI controller — independent rendering task
     * ====================================================================== */
    ui_controller_init(&led_strip, &buzzer, slots, MAX_SENSORS);

    /* ======================================================================
     * LAYER 5: Peripheral services — LoRa RX + Buttons polling
     * ====================================================================== */
    lora_service_init();
    buttons_service_init();

    ESP_LOGI(TAG, "Water Sentry Gateway fully operational.");
    ESP_LOGI(TAG, "Monitoring %d sensor slots.", MAX_SENSORS);
}

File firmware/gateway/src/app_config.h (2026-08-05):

#ifndef APP_CONFIG_H
#define APP_CONFIG_H

/**
 * @brief Unified project configuration.
 *        All magic numbers live here — no duplicates across modules.
 */

#define MAX_SENSORS        5    // Total sensor slots
#define EVENT_QUEUE_LENGTH 10   // System event queue capacity
#define LORA_RX_QUEUE_LENGTH 20 // LoRa RX packet queue capacity

#define BUTTON_POLL_MS      20  // ADC polling interval

#define SENSOR_TIMEOUT_MS   15*60000 // 30 min — sensor considered offline
#define PAIRING_TIMEOUT_MS  60000 // 60 s — pairing mode auto-cancel

#endif // APP_CONFIG_H

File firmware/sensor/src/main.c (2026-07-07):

#include "buzzer_handler.h"
#include "led_handler.h"
#include "link_button_handle.h"
#include "water_sensor_handler.h"
#include "lora_handler.h"
#include "esp_log.h"
#include "freertos/FreeRTOS.h"
#include "freertos/task.h"
#include "gpio_mapping.h"

void app_main(void)
{
    // Будим USB-порт
    vTaskDelay(pdMS_TO_TICKS(2000));

     if (!lora_hw_init())
    {
        ESP_LOGE("MAIN", "Ошибка старта LoRa!");
        return;
    }

    buzzer_init();
    led_init();
    link_button_init();
    water_sensor_init();

    ESP_LOGI("MAIN", "Датчик Sentry узел успешно запущен в работу.");
}

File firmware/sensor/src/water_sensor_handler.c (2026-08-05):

#include "water_sensor_handler.h"
#include "freertos/FreeRTOS.h"
#include "freertos/task.h"
#include "driver/gpio.h"
#include "esp_log.h"
#include "link_button_handle.h" // Для функции generate_unique_id()
#include "lora_handler.h"       // Для отправки пакетов пинга и тревоги
#include "gpio_mapping.h"
#include "hw_id.h"
#include "lora_handler.h"
#include "buzzer_handler.h"

static const char *TAG = "WATER_SENS";

#define SENSOR_POLL_PERIOD_MS 1000      // Проверяем воду каждые 1 сек
#define HEARTBEAT_INTERVAL_MS 5 * 60000 // Интервал отправки пинга раз в 1 мин

#define TICKS_FOR_HEARTBEAT (HEARTBEAT_INTERVAL_MS / SENSOR_POLL_PERIOD_MS) // 25 циклов

static void water_sensor_polling_task(void *pvParameters)
{
    uint32_t unique_id = get_unique_id();

    uint32_t heartbeat_counter = 0;
    bool is_flooded = false;

    ESP_LOGI(TAG, "Задача мониторинга протечки запущена на GPIO %d. Мой ID: 0x%08X", WATER_SENSOR_PIN, unique_id);

    while (1)
    {
        // Считываем текущее состояние сенсора (0 - сухо, 1 - вода)
        bool current_water_state = (gpio_get_level(WATER_SENSOR_PIN) == 1);

        if (current_water_state)
        {
            // =================================================================
            // СИТУАЦИЯ: ОБНАРУЖЕНА ВОДА
            // =================================================================
            if (!is_flooded)
            {
                // Вода обнаружена только что (смена состояния)
                is_flooded = true;
                ESP_LOGE(TAG, "Обнаружена протечка! Мгновенный выстрел тревоги в эфир!");
                for (int i = 0; i <= 5; i++)
                    lora_send_real_alarm_packet(unique_id);

                heartbeat_counter = 0; // Сбрасываем счетчик, чтобы контролировать шаг повторов
                buzz(2);
            }
            else
            {
                // Вода стоит уже давно. Чтобы не сжечь эфир, шлем аварийный пакет
                // раз в период heartbeat_counter (каждые 5 секунд), напоминая базе о беде
                heartbeat_counter++;
                if (heartbeat_counter >= TICKS_FOR_HEARTBEAT)
                {
                    ESP_LOGW(TAG, "Протечка продолжается. Повторная отправка сигнала тревоги...");
                    lora_send_real_alarm_packet(unique_id);
                    heartbeat_counter = 0;
                    buzz(2);
                }
            }
        }
        else
        {
            // =================================================================
            // СИТУАЦИЯ: СУХО
            // =================================================================
            if (is_flooded)
            {
                // Вода ушла (высохло / датчик убрали из лужи)
                is_flooded = false;
                ESP_LOGW(TAG, "Уровень воды пришел в норму (высохло).");

                // Отправляем штатный пинг, чтобы база сразу поняла, что авария снята
                for (int i = 0; i <= 5; i++)
                    lora_send_heartbit_packet(unique_id);

                heartbeat_counter = 0;
            }
            else
            {
                // Всё спокойно, штатный режим. Считаем время до следующего Heartbeat
                heartbeat_counter++;
                if (heartbeat_counter >= TICKS_FOR_HEARTBEAT)
                {
                    lora_send_heartbit_packet(unique_id);
                    heartbeat_counter = 0; // Обнуляем таймер пинга
                }
            }
        }

        // Засыпаем. Процессор отдыхает, FreeRTOS переключается на другие задачи
        vTaskDelay(pdMS_TO_TICKS(SENSOR_POLL_PERIOD_MS));
    }
}

void water_sensor_init()
{
    ESP_LOGI(TAG, "Конфигурация датчика уровня жидкости...");

    gpio_config_t io_conf = {
        .pin_bit_mask = (1ULL << WATER_SENSOR_PIN),
        .mode = GPIO_MODE_INPUT,
        .pull_up_en = GPIO_PULLUP_DISABLE,
        .pull_down_en = GPIO_PULLDOWN_DISABLE,
        .intr_type = GPIO_INTR_DISABLE // Опрос в цикле
    };
    gpio_config(&io_conf);

    // Создаем независимый поток для контроля воды
    xTaskCreate(water_sensor_polling_task, "water_sensor_task", 3072, NULL, 12, NULL);

    ESP_LOGI(TAG, "...датчик уровня жидкости инициализирован.");
}

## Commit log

2026-06-25 all: init
    [active_sender.kicad_pcb, active_sender.kicad_sch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]
2026-07-01 sensor iteration 2
    [active_sender.kicad_pcb, active_sender.kicad_sch]
2026-07-02 sensor iteration 3
    [active_sender.kicad_sch, Блок управления датчиком уровня жидкости.3mf, Корпус блока управления датчика уровня жидкости.stp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]
2026-07-02 gateway init
    [Piezo Buzzer (3-24v, M3).step, active_sender.kicad_pcb, active_sender.kicad_sch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]
2026-07-07 folders structure improved and reorganised
    [Piezo Buzzer (3-24v, M3).step, active_sender.kicad_pcb, active_sender.kicad_sch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]
2026-08-05 added alarm acknowledge and many code improvements
    [active_sender.kicad_pcb, active_sender.kicad_sch, sensor_3d.step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]
2026-08-05 quick fix
    [Базовая станция Исп 1.3mf]
